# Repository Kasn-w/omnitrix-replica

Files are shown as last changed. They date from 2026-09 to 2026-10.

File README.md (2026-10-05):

# Omnitrix
*Built 2024 (Grade 12)*

A wearable replica of the Omnitrix from BEN10 Omniverse, built from a hand sketch through 3D-printed shell to working electronics with display, sound, and WiFi; all functional.

https://github.com/user-attachments/assets/e2240c9e-b4f1-43e2-badf-02dda2eb7e8f

## About
- Sketched the design in a notebook
- Modeled in SketchUp
    - [View 3D model](model/om_omitrix.stl)
    - [SketchUp online view](https://app.sketchup.com/share/tc/asia/PURIXS78B2o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)
- 3D printed the shell
- ESP32-S2 Mini wired to a TFT screen and a speaker
- Can be powered using two 12V 23A alkaline cells (wired in parallel)

## What It Does
- **Play Feature** —  physical buttons drive an on-screen menu and animations to cycle between 8 alien icons synced with sound effects
    - *There are 4 buttons, 3 on the side and 1 behind the screen to allow you to activate the omnitrix just like in the show*
- **WiFi Setup** — connects via a captive portal (using the WiFiManager library) so it can be configured from a phone, no hardcoded credentials
- **Time Lookup** — syncs time over NTP and display it on the screen

## Component
- ESP32-S2 Mini
- TFT 1.3 inch
- LM386 Audio Amplifier
- Speaker (collected from broken earbuds)
- Wires (collected from broken earbuds)
- 5V Buck converter

## Wiring

| Component | Signal | GPIO Pin |
|---|---|---|
| Display (TFT) | MOSI | 11 |
| Display (TFT) | SCLK | 7 |
| Display (TFT) | CS | 6 |
| Display (TFT) | DC | 35 |
| Display (TFT) | RST | 39 |
| Display (TFT) | Backlight | 16 |
| LM386 (audio amp) | BCLK/WSEL | 5 |
| LM386 (audio amp) | Data | 17 |
| Buttons | 4x inputs | 3, 4, 18, 21 |

**This pinout was reconstructed from the code.*

## Built With
- Arduino IDE 1.8.19
- ESP32 board package (Espressif) v2.0.17, board set to "LOLIN S2 Mini"
- Libraries: TFT_eSPI, WiFiManager, ESP8266Audio
    - working copies included in `_library/` (see below)

## Constraints
- The ESP32-S2 Mini's flash storage filled up fast because of audio, bitmap graphics and code combined — final build used **99%** of available program storage. I coded main screen to be draw manually instead of storing it as bitmap like the icons, to lower the storage used.

- The sound this build can produce is quite quiet because the speaker is collected from earbud. Making it hard to hear if in a loud environment.

- Battery choice (23A cells) was picked for its small size to keep the build wearable. Even so, the battery tray ended up being the second-largest component. This also makes its runtime pretty short, around 2-3 minutes per pair of cells.

## Library Credits
`_library/` contains known-working copies of each dependency, since exact original versions aren't otherwise documented and newer releases aren't confirmed to work:
- [TFT_eSPI](https://github.com/Bodmer/TFT_eSPI)
- [WiFiManager](https://github.com/tzapu/WiFiManager)
- [ESP8266Audio](https://github.com/earlephilhower/ESP8266Audio)

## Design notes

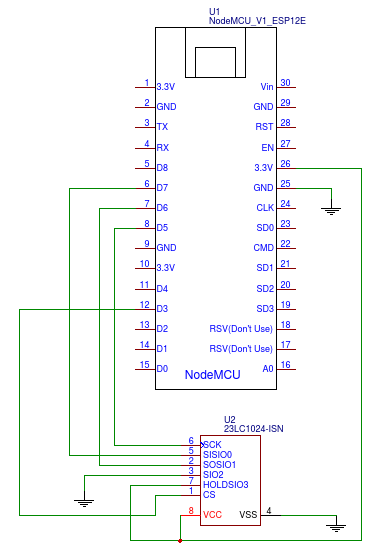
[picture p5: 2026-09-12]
_library/ESP8266Audio/examples/StreamMP3FromHTTP_SPIRAM/Schema_Spiram.png

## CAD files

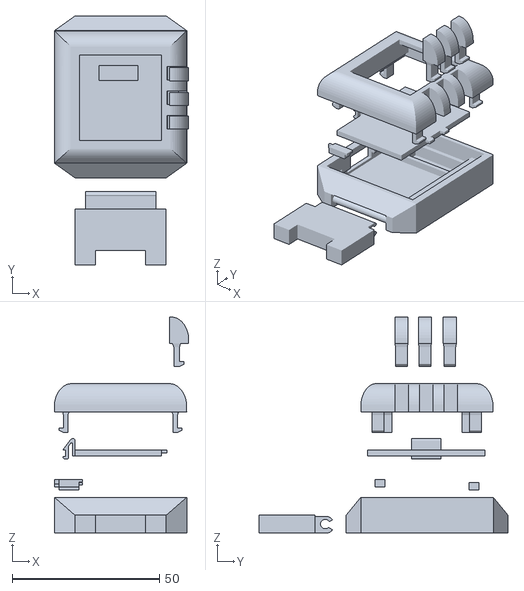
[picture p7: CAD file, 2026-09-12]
model/om_omitrix.stl
45.7 x 84.6 x 73.3

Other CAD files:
model/om_omitrix.skp

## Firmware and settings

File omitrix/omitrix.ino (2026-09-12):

#include <TFT_eSPI.h>
#include <WiFiManager.h>
#include<WiFi.h>
#include <time.h>
#include "AudioFileSourcePROGMEM.h"
#include "AudioGeneratorWAV.h"
#include "AudioOutputI2SNoDAC.h"

#include "omicore.h"
#include "activate.h"
#include "openup.h"
#include "selecte.h"
#include "tranform.h"
#include "wait.h"
#include "icon7.h"

#define I2S_SPEAKER_SERIAL_CLOCK GPIO_NUM_5 // BCLK
#define I2S_SPEAKER_LEFT_RIGHT_CLOCK GPIO_NUM_5 // WSEL
#define I2S_SPEAKER_SERIAL_DATA GPIO_NUM_17       // pin 17 on the ESP32S2 where the speaker is connected

AudioGeneratorWAV *wav;
AudioFileSourcePROGMEM *file;
AudioOutputI2SNoDAC *out;

int bt[] = {3,4,18,21};
const int btrange = sizeof(bt)/sizeof(bt[0]);

int mod, rotacount, omcount;
int modc = 1;
String ltime, ldate;

TFT_eSPI ipsdisp= TFT_eSPI();           

void setup() {
  Serial.begin(115200);
  for(int i = 0;i < btrange ; i++){
    Serial.println(String(bt[i]) + " pin");
    pinMode(bt[i], INPUT); 
  }

  esp_sleep_enable_ext0_wakeup(GPIO_NUM_3,1); 

  file = new AudioFileSourcePROGMEM( activate, sizeof(activate) );
  out = new AudioOutputI2SNoDAC();
  out -> SetPinout(I2S_SPEAKER_SERIAL_CLOCK, I2S_SPEAKER_LEFT_RIGHT_CLOCK, I2S_SPEAKER_SERIAL_DATA);
  wav = new AudioGeneratorWAV();
  wav->begin(file, out);
  
  ipsdisp.begin();             //Initiatise SPI Bus
  ipsdisp.init();              //Initialise ST7789
  ipsdisp.setRotation(rotacount);      //Value 1 means landescape mode; Value 2 means potrait mode
  ipsdisp.setSwapBytes(true);  //Swap the byte order for pushImage() - corrects endianness
  ipsdisp.fillScreen(TFT_BLACK);

}

void loop() {
  //Trigger Once
  if (mod != modc){
    mod = modc;
    switch (mod){
      case 1 :
      //ipsdisp.pushImage(0,0,240,240,om);  //ipsdisp.pushImage(x1,y1,x2,y2,array of image 3 containting 16-bit RGB565 data of each pixel) 
        Disom();
        delay(100);
        break;
      case 2:
        Disom();
        ipsdisp.fillRect(25,70,193,102,TFT_GREEN); ipsdisp.fillRect(30,75,183,92,TFT_BLACK);

        ipsdisp.setTextColor(TFT_GREEN);
        for(int i = 0;i < 3 ; i++){
          ipsdisp.setCursor(60 + (i * 40),50,8);
          ipsdisp.print(".");
          Wifi_setup(false);
          delay(60);
        }

        Gettime();
        delay(100);
        ipsdisp.setTextColor(TFT_WHITE);
        ipsdisp.fillRect(20,23,200,194,TFT_GREEN); ipsdisp.fillRect(25,28,190,184,TFT_BLACK);
        ipsdisp.drawCentreString(ltime,120,67 ,7);
        ipsdisp.drawCentreString(ldate,120,132 ,4);
        break;
      case 10:
        ipsdisp.pushImage(39,39,165,165,core);
        omcount = 2;
        while ((digitalRead(4) == LOW)&&(digitalRead(21) == LOW)){
          if (wav->isRunning()){
            if (!wav->loop()) wav->stop();
          }else{
            Serial.printf("WAV done\n");
            Serial.print("count 2 = " + String(omcount));
            if (omcount == 2){ file = new AudioFileSourcePROGMEM( openup, sizeof(openup) ); omcount += 1;
            }else if (omcount == 3) file = new AudioFileSourcePROGMEM( wait, sizeof(wait) );
          
            out = new AudioOutputI2SNoDAC();
            out -> SetPinout(I2S_SPEAKER_SERIAL_CLOCK, I2S_SPEAKER_LEFT_RIGHT_CLOCK, I2S_SPEAKER_SERIAL_DATA);
      
            wav = new AudioGeneratorWAV();
            wav->begin(file, out);      
          }
        }
        ipsdisp.fillScreen(TFT_GREEN);
        omcount = 4;
        Serial.printf("WAV done\n");
        Serial.print("count 3 = " + String(omcount));
          
        file = new AudioFileSourcePROGMEM( tranform, sizeof(tranform) );
          
        out = new AudioOutputI2SNoDAC();
        out -> SetPinout(I2S_SPEAKER_SERIAL_CLOCK, I2S_SPEAKER_LEFT_RIGHT_CLOCK, I2S_SPEAKER_SERIAL_DATA);
      
        wav = new AudioGeneratorWAV();
        wav->begin(file, out);  
    
        while (omcount == 4){
          if (wav->isRunning()){
            if (!wav->loop()) wav->stop();
          }else omcount = 0; modc = 1;
        }
        delay(80);
        break;
     }
  }else{  //---------------------- LOOP ----------------------------
    switch (mod){
      case 1:
      int i;
      i = 0;
      if ((digitalRead(4) == HIGH)||(digitalRead(21) == HIGH)){
        ipsdisp.fillScreen(TFT_BLACK);
        ipsdisp.pushImage(39,39,165,165,core);
        ipsdisp.fillCircle(120, 120, 73, TFT_BLACK);
        mod = 0;
      }
      while ((digitalRead(4) == HIGH)||(digitalRead(21) == HIGH)){
        if (wav->isRunning()){
          if (!wav->loop()) wav->stop();
        }else{
          Serial.printf("WAV done\n");
          Serial.print("count 1 = " + String(omcount));
          if (omcount == 0){ file = new AudioFileSourcePROGMEM( activate, sizeof(activate) ); omcount = 1;
          }else if (omcount == 1) file = new AudioFileSourcePROGMEM( selecte, sizeof(selecte) ); modc = 10;
          
          out = new AudioOutputI2SNoDAC();
          out -> SetPinout(I2S_SPEAKER_SERIAL_CLOCK, I2S_SPEAKER_LEFT_RIGHT_CLOCK, I2S_SPEAKER_SERIAL_DATA);
      
          wav = new AudioGeneratorWAV();
          wav->begin(file, out);
          i ++;
          if (i > 7) i = 0;
          ipsdisp.pushImage(70,70,100,100,icon7[i]);
          delay(80);
        }
      }
      break;
      case 2:
      if (digitalRead(4) == HIGH){
        rotacount += 1; 
        if (rotacount > 3) rotacount = 0;
        ipsdisp.setRotation(rotacount);
        mod = 0;
      }else if (digitalRead(21) == HIGH){
        ipsdisp.fillScreen(TFT_BLACK);
        ipsdisp.drawCentreString("Going to sleep",120,40 ,4); ipsdisp.drawCentreString("Prees to stop",120,180 ,4);
        unsigned long time1 = millis(); int sumtime;
        delay(100);
        while ((digitalRead(3) == LOW)&&(digitalRead(4) == LOW)&&(digitalRead(18) == LOW)&&(digitalRead(21) == LOW)){
          unsigned long time2 = millis();
          int sumtimec = sumtime;
          sumtime = 10 - ((time2 - time1) / 1000);
          if (sumtime != sumtimec) ipsdisp.fillRect(0,70,240,100,TFT_BLACK);
          ipsdisp.drawCentreString(String(sumtime),120,100 ,7);
          if (sumtime <= 0){
            ipsdisp.fillScreen(TFT_BLACK); 
            esp_deep_sleep_start(); }
          delay(100);
        }mod = 0;
      }
      break;
    }
  }
       
  if (digitalRead(3) == HIGH){
    modc += 1;
    if (modc > 2) modc = 1;
  }else if (digitalRead(18) == HIGH){
    Wifi_setup(true);
  }

  Serial.print("mod : ");
  Serial.println(mod);
  if (wav->isRunning()){
    if (!wav->loop()) wav->stop();}
  delay(70);
}

void Disom(){
  ipsdisp.fillScreen(TFT_BLACK);
  ipsdisp.fillTriangle(78,120,0,-55,0,295,TFT_GREEN); ipsdisp.fillTriangle(48,120,0,35,0,205,TFT_BLACK);
  ipsdisp.fillTriangle(162,120,240,-55,240,295,TFT_GREEN); ipsdisp.fillTriangle(192,120,240,35,240,205,TFT_BLACK);
}

void Gettime(){
  WiFiClient Client;
  String tmi; String tse;
  configTime(7 * 3600, 0, "pool.ntp.org", "time.nist.gov");
  Serial.println("\nLoading time");
  while (!time(nullptr)) { Serial.print("*"); delay(1000);}
    
  time_t now = time(nullptr); struct tm* p_tm = localtime(&now);
  delay(100);
  tmi = String(p_tm->tm_min); tse = String(p_tm->tm_sec);
  if (p_tm->tm_min < 10) tmi = "0" + tmi;
  if (p_tm->tm_sec < 10)tse = "0" + tse;
  
  ltime = String(p_tm->tm_hour) + " : " + tmi;
  ldate = String(p_tm->tm_mday) + "/" + String(p_tm->tm_mon + 1) + "/" + String(p_tm->tm_year + 2443);
}


void Wifi_setup(bool x){
  WiFi.mode(WIFI_STA);
  WiFiManager wm;
  bool res;
  if (x == false) {
    res = wm.autoConnect("Omitrix");
    Serial.println(res);
    if(!res) modc = 15;
  }else wm.resetSettings();
}

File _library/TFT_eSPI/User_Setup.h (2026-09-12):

/*Typical pin layout used:
 * ---------------------------------------------
 * Signal               ST7789 IPS    ESP8266
 *                      Module        Interface
 *                      Pin           Pin
 * ---------------------------------------------
 * VCC(3.3V)            VCC           3V3
 * GND(Ground)          GND           GND
 * SDA(Serial Data)     DIN           D7(MOSI)
 * SLK(Serial Clock)    CLK           D5(SCLK)
 * CS(Chip Select)      CS            D8(CS)
 * DC(Data/Command)     DC            D0
 * RST(Reset)           RST           D1
 * BL(Backlight)        BL            D2
  */

#define ST7789_DRIVER      

#define TFT_RGB_ORDER TFT_BGR  // Colour order Blue-Green-Red to display 

#define TFT_WIDTH  240 // ST7789 240 x 320 resolution

#define TFT_HEIGHT 320 // ST7789 240 x 320 resolution

#define TFT_INVERSION_ON

#define TFT_BACKLIGHT_ON HIGH  // HIGH or LOW are options

#define TFT_MOSI 11 // In some display driver board, it might be written as "SDA" and so on.
#define TFT_SCLK 7
#define TFT_CS   6  // Chip select control pin
#define TFT_DC   35  // Data Command control pin
#define TFT_RST  39  // Reset pin (could connect to Arduino RESET pin)
#define TFT_BL   16  // LED back-light

#define LOAD_GLCD   // Font 1. Original Adafruit 8 pixel font needs ~1820 bytes in FLASH
#define LOAD_FONT2  // Font 2. Small 16 pixel high font, needs ~3534 bytes in FLASH, 96 characters
#define LOAD_FONT4  // Font 4. Medium 26 pixel high font, needs ~5848 bytes in FLASH, 96 characters
#define LOAD_FONT6  // Font 6. Large 48 pixel font, needs ~2666 bytes in FLASH, only characters 1234567890:-.apm
#define LOAD_FONT7  // Font 7. 7 segment 48 pixel font, needs ~2438 bytes in FLASH, only characters 1234567890:-.
#define LOAD_FONT8  // Font 8. Large 75 pixel font needs ~3256 bytes in FLASH, only characters 1234567890:-.
#define SMOOTH_FONT

#define SPI_FREQUENCY  27000000 // Actually sets it to 26.67MHz = 80/3


#define SPI_READ_FREQUENCY  20000000 // Optional reduced SPI frequency for reading TFT

// The XPT2046 requires a lower SPI clock rate of 2.5MHz so we define that here:
#define SPI_TOUCH_FREQUENCY  2500000

#define SUPPORT_TRANSACTIONS
